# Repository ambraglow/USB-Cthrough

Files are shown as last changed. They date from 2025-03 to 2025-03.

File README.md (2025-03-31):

# USB Cthrough

## Notes

- Pin headers are arranged in a way that this board can be plugged into a breadboard.
- Signal names are silkscreened on the board, top and bottom layers.
- This repository also includes files for manufacturing a 2x3 panel.
- I recommend a stencil for assembling this board.

## Info

- Software: Kicad 8
- Version: 3
- PCB size: 32.5x28mm
- Layer count: 6
- Recommended thickness: 0.8mm (for the USB-C plug)

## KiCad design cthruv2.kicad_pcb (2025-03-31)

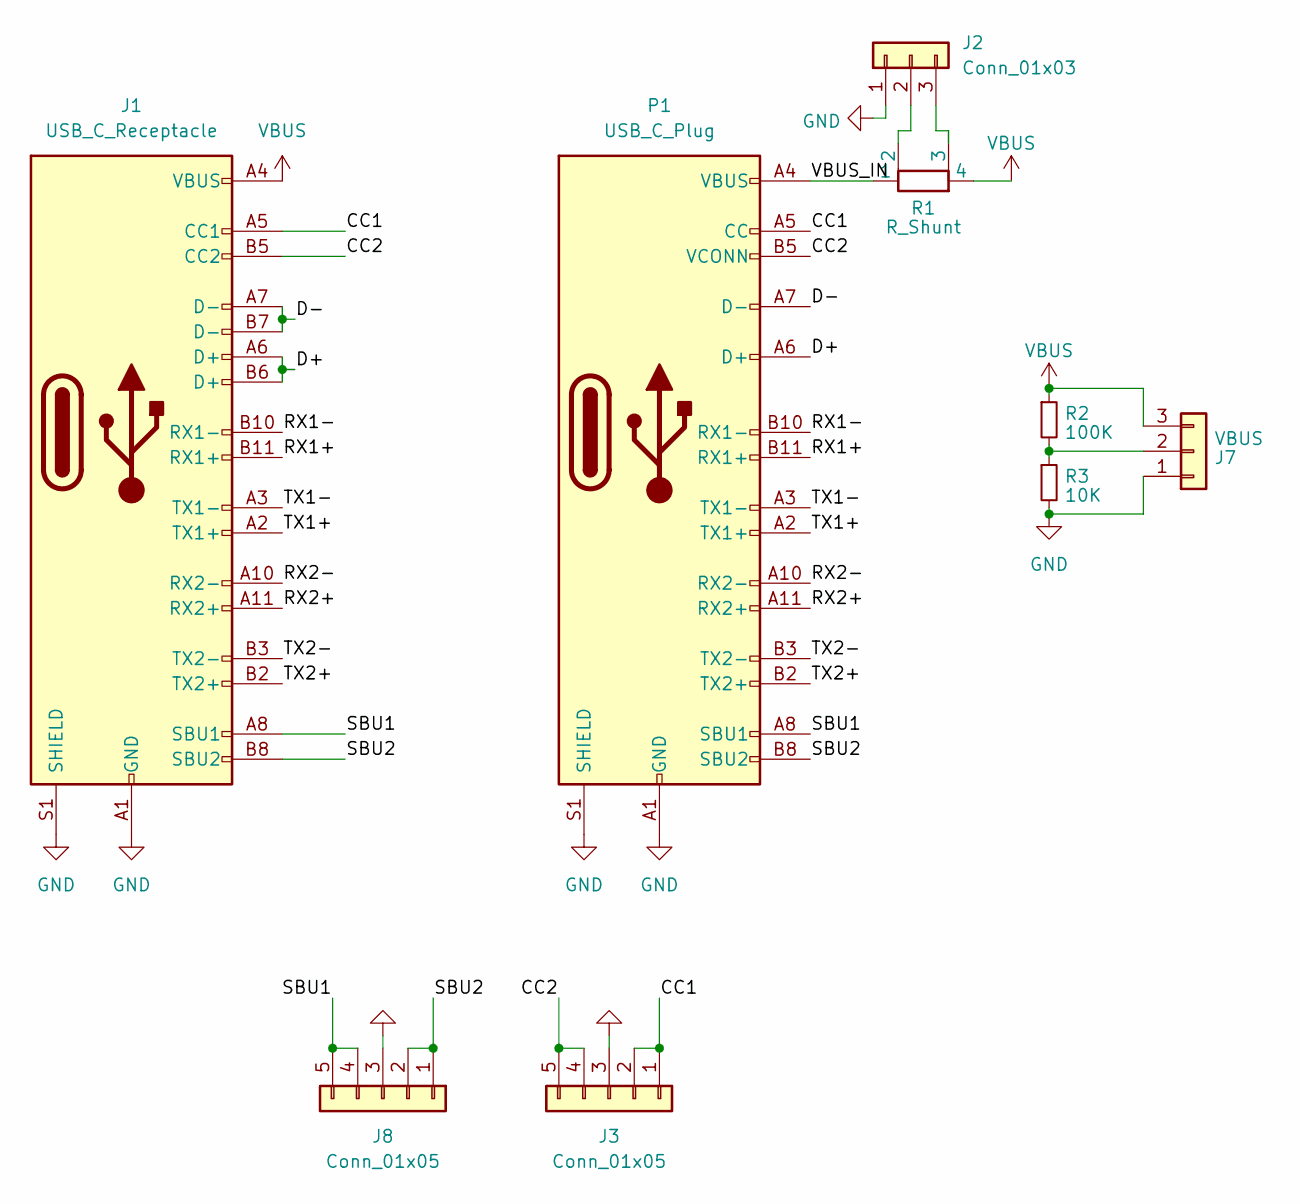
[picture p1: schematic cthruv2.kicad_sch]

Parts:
J1: USB_C_Receptacle; USB_C_Receptacle_Amphenol_12401548E4-2A; LCSC_ID C709359
J2: Conn_01x03; PinHeader_1x03_P2.54mm_Vertical
J3, J8: Conn_01x05; PinHeader_1x05_P2.54mm_Vertical
J7: VBUS; PinHeader_1x03_P2.54mm_Vertical
P1: USB_C_Plug; USB_C_Plug_Molex_105444; LCSC_ID C319150
R1: R_Shunt; Shunt; LCSC_ID C175856
R2: 100K; R_0603_1608Metric; LCSC_ID C25803
R3: 10K; R_0603_1608Metric; LCSC_ID C25804

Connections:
/CC1: J1.A5 (CC1), J3.1, J3.2, P1.A5 (CC)
/CC2: J1.B5 (CC2), J3.4, J3.5, P1.B5 (VCONN)
/D+: J1.A6 (D+), J1.B6 (D+), P1.A6 (D+)
/D-: J1.A7 (D-), J1.B7 (D-), P1.A7 (D-)
/RX1+: J1.B11 (RX1+), P1.B11 (RX1+)
/RX1-: J1.B10 (RX1-), P1.B10 (RX1-)
/RX2+: J1.A11 (RX2+), P1.A11 (RX2+)
/RX2-: J1.A10 (RX2-), P1.A10 (RX2-)
/SBU1: J1.A8 (SBU1), J8.4, J8.5, P1.A8 (SBU1)
/SBU2: J1.B8 (SBU2), J8.1, J8.2, P1.B8 (SBU2)
/TX1+: J1.A2 (TX1+), P1.A2 (TX1+)
/TX1-: J1.A3 (TX1-), P1.A3 (TX1-)
/TX2+: J1.B2 (TX2+), P1.B2 (TX2+)
/TX2-: J1.B3 (TX2-), P1.B3 (TX2-)
/VBUS_IN: P1.A4 (VBUS), P1.A9 (VBUS), P1.B4 (VBUS), P1.B9 (VBUS), R1.1
GND: J1.A1 (GND), J1.A12 (GND), J1.B1 (GND), J1.B12 (GND), J1.S1 (SHIELD), J2.1, J3.3, J7.1, J8.3, P1.A1 (GND), P1.A12 (GND), P1.B1 (GND), P1.B12 (GND), P1.S1 (SHIELD), R3.2
unnamed: J2.2, R1.2
unnamed: J2.3, R1.3
unnamed: J7.2, R2.2, R3.1
VBUS: J1.A4 (VBUS), J1.A9 (VBUS), J1.B4 (VBUS), J1.B9 (VBUS), J7.3, R1.4, R2.1

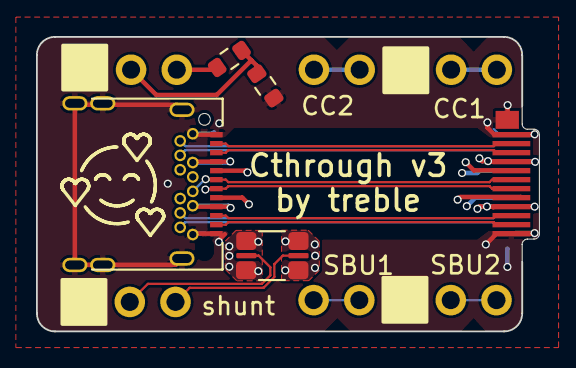
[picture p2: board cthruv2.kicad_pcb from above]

Board: 6 copper layers, 27.9 x 16.4 mm, 9 parts (0 on the bottom side), 20 nets.

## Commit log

2025-03-31 v3: rerouted pin header pinout, improved routing
    [cthruv2.kicad_pcb, cthruv2.kicad_sch]
2025-03-31 panel json file: JLCPCB, 2x3, extended PCBA (=> >70x70 size panel)
2025-03-31 small insignificant fix (two unused keepouts removed from outside the board area)
    [cthruv2.kicad_pcb]
